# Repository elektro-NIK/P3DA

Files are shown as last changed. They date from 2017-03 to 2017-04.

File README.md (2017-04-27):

# P3DA

This is RGB controller based on Arduino board.

Features:
- 6 RGB chanels (18 mono-chanels)
- common anode or cathode
- light, effect, sound, external backlight modes
- white balance, gamma correction

Install:
- `pip3 install PyQt5` and `python3 setup.py install` for use in your system
- or `pip3 install -e .` for install all necessary modules

Using: 
- `./software/main.py` for starting
- `/software/test.py` test rainbow ilumination on 0 channel

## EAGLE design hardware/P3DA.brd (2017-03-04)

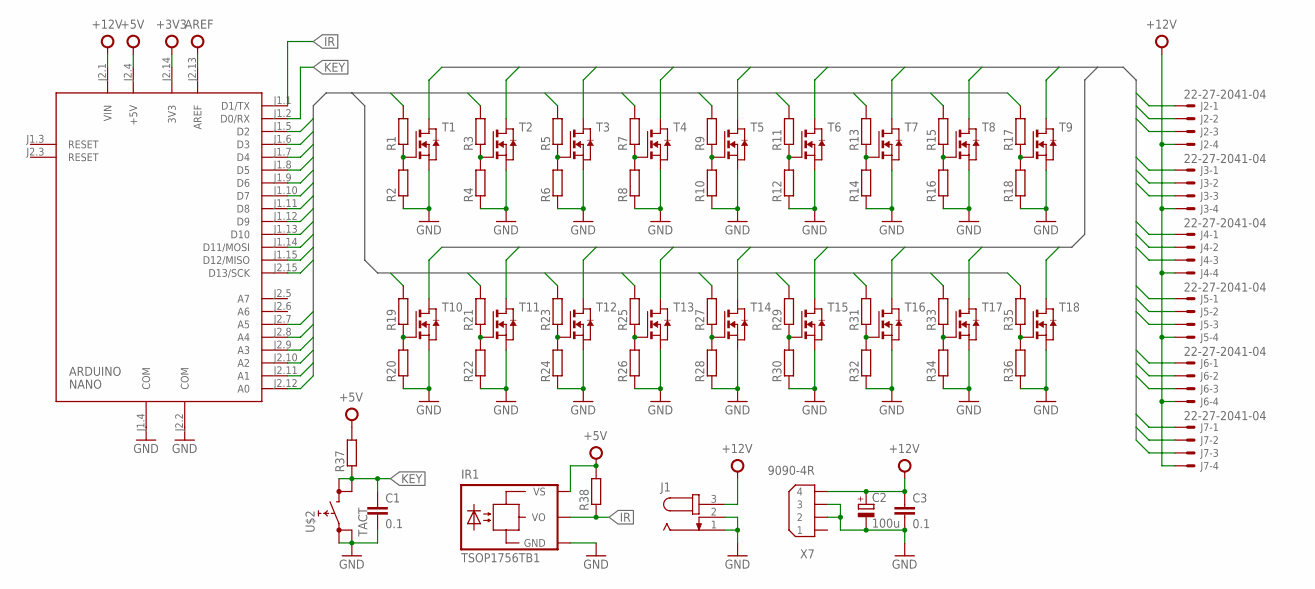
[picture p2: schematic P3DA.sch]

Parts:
ARDUINO: NANO; ARDUINO_NANO2
C1: 0.1; C0805
C2: 100u; E5-13
C3: 0.1; C1206
IR1: TSOP1756TB1; TSOP17_TB1
J1: JACK-PLUG1; SPC4078
J2, J3, J4, J5, J6, J7: 22-27-2041-04; 6410-04
R1, R2, R3, R4, R5, R6, R7, R8, R9, R10, R11, R12, R13, R14, R15, R16, R17, R18, R19, R20, R21, R22, R23, R24, R25, R26, R27, R28, R29, R30, R31, R32, R33, R34, R35, R36, R37, R38: R-EU_R0805; R0805
T1, T2, T3, T4, T5, T6, T7, T8, T9, T10, T11, T12, T13, T14, T15, T16, T17, T18: NMOSSOT23; SOT-23
U$2: TACT; TL1105
X7: 9090-4R

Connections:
+3V3: ARDUINO.J2.14 (3V3)
+5V: ARDUINO.J2.4 (+5V), IR1.VS, R37.2, R38.2
+12V: ARDUINO.J2.1 (VIN), C2.+, C3.1, J1.3, J2.4, J3.4, J4.4, J5.4, J6.4, J7.4, X7.4
AREF: ARDUINO.J2.13 (AREF)
B1: J2.1, T3.1 (D)
B2: J3.1, T6.1 (D)
B3: J4.1, T9.1 (D)
B4: J5.1, T12.1 (D)
B5: J6.1, T15.1 (D)
B6: J7.1, T18.1 (D)
B_IN1: ARDUINO.J1.5 (D2), R5.2
B_IN2: ARDUINO.J1.8 (D5), R11.2
B_IN3: ARDUINO.J1.11 (D8), R17.2
B_IN4: ARDUINO.J2.9 (A3), R23.2
B_IN5: ARDUINO.J2.12 (A0), R29.2
B_IN6: ARDUINO.J1.15 (D12/MISO), R35.2
G1: J2.3, T2.1 (D)
G2: J3.3, T5.1 (D)
G3: J4.3, T8.1 (D)
G4: J5.3, T11.1 (D)
G5: J6.3, T14.1 (D)
G6: J7.3, T17.1 (D)
GND: ARDUINO.J1.4 (COM), ARDUINO.J2.2 (COM), C1.2, C2.-, C3.2, IR1.GND, J1.1, J1.2, R2.1, R4.1, R6.1, R8.1, R10.1, R12.1, R14.1, R16.1, R18.1, R20.1, R22.1, R24.1, R26.1, R28.1, R30.1, R32.1, R34.1, R36.1, T1.2 (S), T2.2 (S), T3.2 (S), T4.2 (S), T5.2 (S), T6.2 (S), T7.2 (S), T8.2 (S), T9.2 (S), T10.2 (S), T11.2 (S), T12.2 (S), T13.2 (S), T14.2 (S), T15.2 (S), T16.2 (S), T17.2 (S), T18.2 (S), U$2.1 (0), U$2.3 (0), X7.2, X7.3
G_IN1: ARDUINO.J1.7 (D4), R3.2
G_IN2: ARDUINO.J1.10 (D7), R9.2
G_IN3: ARDUINO.J1.13 (D10), R15.2
G_IN4: ARDUINO.J2.7 (A5), R21.2
G_IN5: ARDUINO.J2.10 (A2), R27.2
G_IN6: ARDUINO.J2.15 (D13/SCK), R33.2
IR: ARDUINO.J1.1 (D1/TX), IR1.VO, R38.1
KEY: ARDUINO.J1.2 (D0/RX), C1.1, R37.1, U$2.2 (1), U$2.4 (1)
unnamed: R7.1, R8.2, T4.3 (G)
unnamed: R9.1, R10.2, T5.3 (G)
unnamed: R5.1, R6.2, T3.3 (G)
unnamed: R11.1, R12.2, T6.3 (G)
unnamed: R13.1, R14.2, T7.3 (G)
unnamed: R15.1, R16.2, T8.3 (G)
unnamed: R17.1, R18.2, T9.3 (G)
unnamed: R19.1, R20.2, T10.3 (G)
unnamed: R21.1, R22.2, T11.3 (G)
unnamed: R23.1, R24.2, T12.3 (G)
unnamed: R25.1, R26.2, T13.3 (G)
unnamed: R27.1, R28.2, T14.3 (G)
unnamed: R29.1, R30.2, T15.3 (G)
unnamed: R31.1, R32.2, T16.3 (G)
unnamed: R33.1, R34.2, T17.3 (G)
unnamed: R35.1, R36.2, T18.3 (G)
unnamed: R1.1, R2.2, T1.3 (G)
unnamed: R3.1, R4.2, T2.3 (G)
R1: J2.2, T1.1 (D)
R2: J3.2, T4.1 (D)
R3: J4.2, T7.1 (D)
R4: J5.2, T10.1 (D)
R5: J6.2, T13.1 (D)
R6: J7.2, T16.1 (D)
R_IN1: ARDUINO.J1.6 (D3), R1.2
R_IN2: ARDUINO.J1.9 (D6), R7.2
R_IN3: ARDUINO.J1.12 (D9), R13.2
R_IN4: ARDUINO.J2.8 (A4), R19.2
R_IN5: ARDUINO.J2.11 (A1), R25.2
R_IN6: ARDUINO.J1.14 (D11/MOSI), R31.2

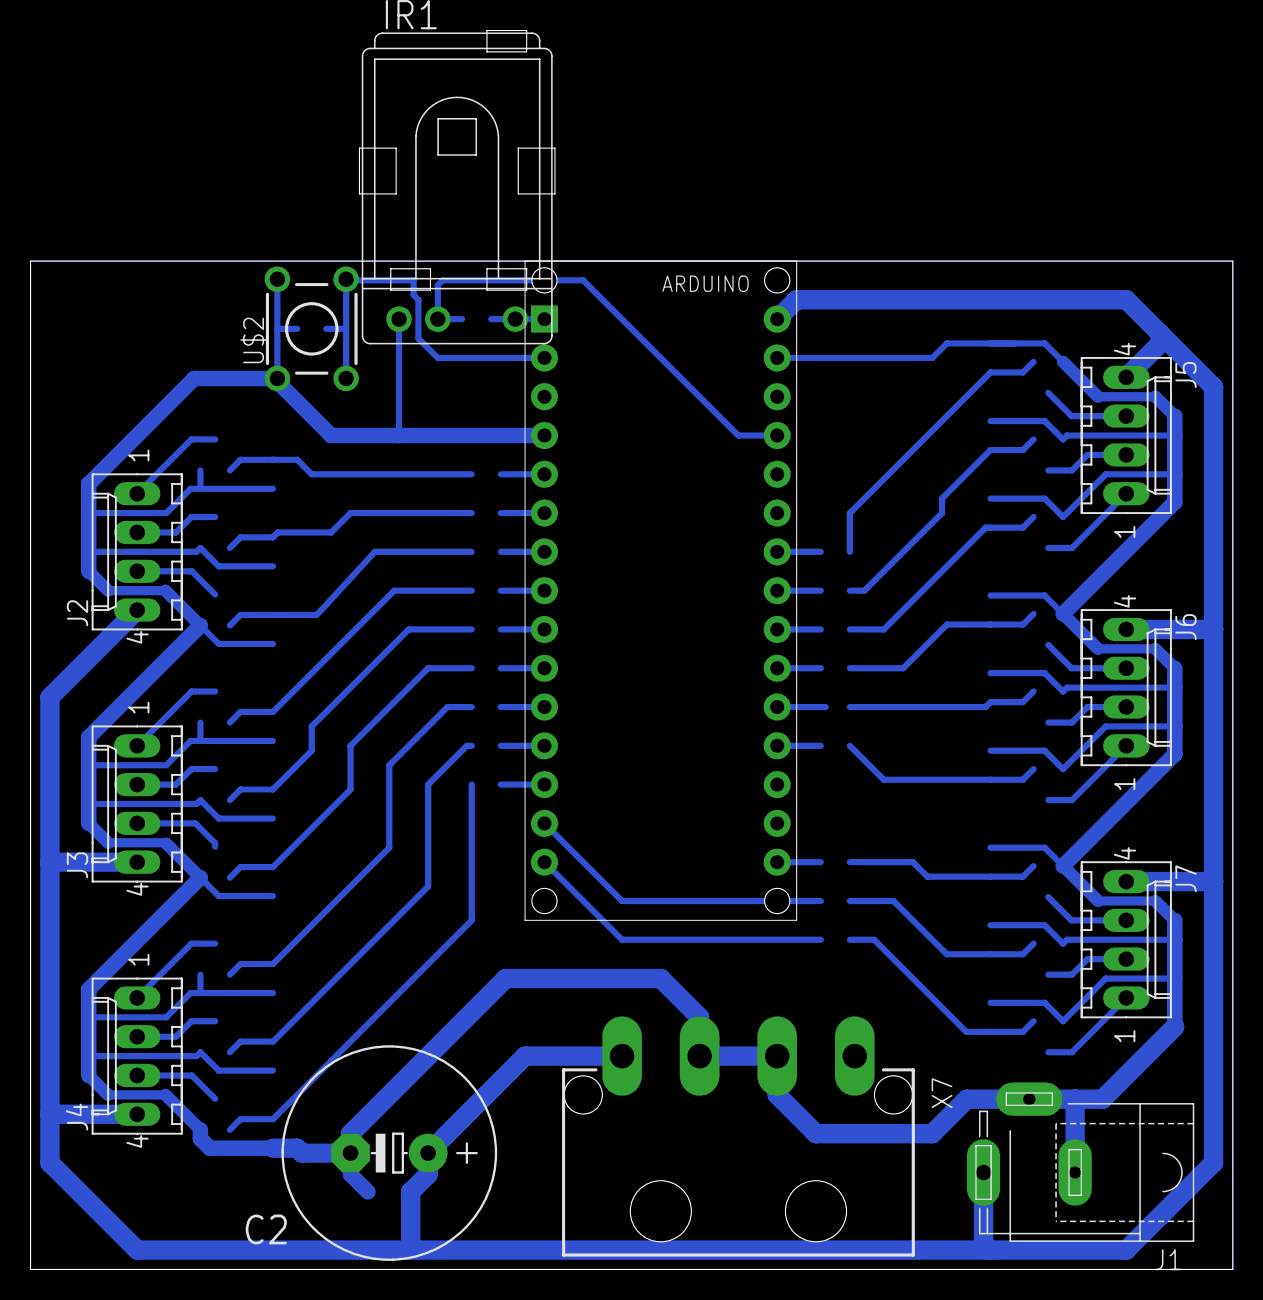
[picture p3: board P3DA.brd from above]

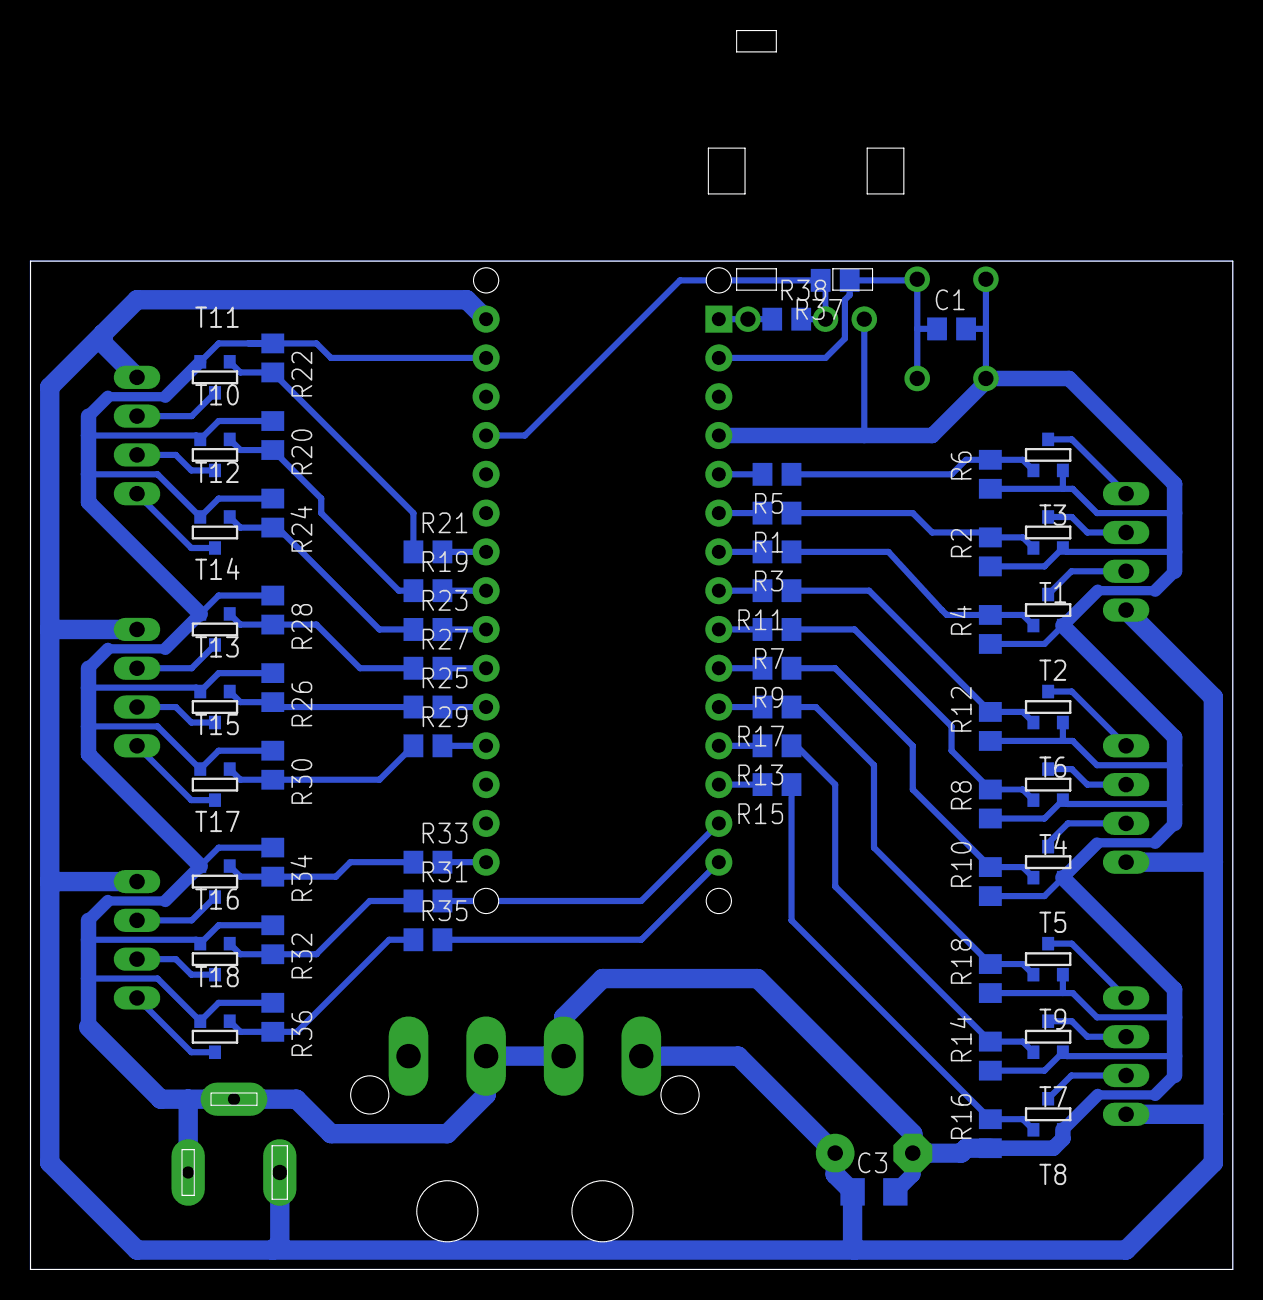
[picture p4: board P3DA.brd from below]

Board: 2 copper layers, 78.7 x 66.0 mm, 70 parts (58 on the bottom side), 59 nets.

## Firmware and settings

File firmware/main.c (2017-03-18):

/*@{*/ // Ports setup
#define DDR_RED0    DDRD
#define DDR_GREEN0  DDRD
#define DDR_BLUE0   DDRD
#define DDR_RED1    DDRD
#define DDR_GREEN1  DDRD
#define DDR_BLUE1   DDRD
#define DDR_RED2    DDRB
#define DDR_GREEN2  DDRB
#define DDR_BLUE2   DDRB
#define DDR_RED3    DDRB
#define DDR_GREEN3  DDRB
#define DDR_BLUE3   DDRB
#define DDR_RED4    DDRC
#define DDR_GREEN4  DDRC
#define DDR_BLUE4   DDRC
#define DDR_RED5    DDRC
#define DDR_GREEN5  DDRC
#define DDR_BLUE5   DDRC

#define PORT_RED0   PORTD
#define PORT_GREEN0 PORTD
#define PORT_BLUE0  PORTD
#define PORT_RED1   PORTD
#define PORT_GREEN1 PORTD
#define PORT_BLUE1  PORTD
#define PORT_RED2   PORTB
#define PORT_GREEN2 PORTB
#define PORT_BLUE2  PORTB
#define PORT_RED3   PORTB
#define PORT_GREEN3 PORTB
#define PORT_BLUE3  PORTB
#define PORT_RED4   PORTC
#define PORT_GREEN4 PORTC
#define PORT_BLUE4  PORTC
#define PORT_RED5   PORTC
#define PORT_GREEN5 PORTC
#define PORT_BLUE5  PORTC

#define RED0        PD3
#define GREEN0      PD4
#define BLUE0       PD2
#define RED1        PD6
#define GREEN1      PD7
#define BLUE1       PD5
#define RED2        PB1
#define GREEN2      PB2
#define BLUE2       PB0
#define RED3        PB3
#define GREEN3      PB5
#define BLUE3       PB4
#define RED4        PC1
#define GREEN4      PC2
#define BLUE4       PC0
#define RED5        PC4
#define GREEN5      PC5
#define BLUE5       PC3
/*@}*/

/*@{*/ // LEDs setup
#define RED         0
#define GREEN       1
#define BLUE        2
#define CATHODE     0
#define ANODE       1

#define COLORS      3
#define CHANELS     6
#define COMMON      CATHODE                 // Common electrode in RGB. CATHODE or ANODE
/*@}*/

/*@{*/ // PWM setup
#define PWMDEPTH    9
#define MAXPWM      511                 // (2^PWMDEPTH) - 1
/*@}*/

/*@{*/ // USART setup
#define BAUD 38400

#define USART_RX_BUFFER_SIZE 128            // 2,4,8,16,32,64,128 or 256 bytes
#define USART_TX_BUFFER_SIZE 128            // 2,4,8,16,32,64,128 or 256 bytes
#define USART_RX_BUFFER_MASK (USART_RX_BUFFER_SIZE - 1)
#define USART_TX_BUFFER_MASK (USART_TX_BUFFER_SIZE - 1)

#if (USART_RX_BUFFER_SIZE & USART_RX_BUFFER_MASK)
#error RX buffer size is not a power of 2
#endif
#if (USART_TX_BUFFER_SIZE & USART_TX_BUFFER_MASK)
#error TX buffer size is not a power of 2
#endif
/*@}*/

#include <avr/io.h>
#include <avr/interrupt.h>
#include <util/setbaud.h>

/*@{*/ // Global variables
static uint8_t USART_RxBuf[USART_RX_BUFFER_SIZE];
static volatile uint8_t USART_RxHead;
static volatile uint8_t USART_RxTail;
static uint8_t USART_TxBuf[USART_TX_BUFFER_SIZE];
static volatile uint8_t USART_TxHead;
static volatile uint8_t USART_TxTail;

volatile uint16_t leds[COLORS][CHANELS];              // Values RGB LEDs. User changeble
uint16_t leds_buff[COLORS][CHANELS];         // Protected buffer RGB values. Program use only
volatile uint16_t countPWM = 0;                       // Counter for software PWM
/*@}*/

/*@{*/ // Functions section

void InitPorts() {
    DDR_RED0 |= 1<<RED0;
    DDR_RED1 |= 1<<RED1;
    DDR_RED2 |= 1<<RED2;
    DDR_RED3 |= 1<<RED3;
    DDR_RED4 |= 1<<RED4;
    DDR_RED5 |= 1<<RED5;
    DDR_GREEN0 |= 1<<GREEN0;
    DDR_GREEN1 |= 1<<GREEN1;
    DDR_GREEN2 |= 1<<GREEN2;
    DDR_GREEN3 |= 1<<GREEN3;
    DDR_GREEN4 |= 1<<GREEN4;
    DDR_GREEN5 |= 1<<GREEN5;
    DDR_BLUE0 |= 1<<BLUE0;
    DDR_BLUE1 |= 1<<BLUE1;
    DDR_BLUE2 |= 1<<BLUE2;
    DDR_BLUE3 |= 1<<BLUE3;
    DDR_BLUE4 |= 1<<BLUE4;
    DDR_BLUE5 |= 1<<BLUE5;
}

void USART0_Init() {
    UBRR0H = UBRRH_VALUE;
    UBRR0L = UBRRL_VALUE;
    #if USE_2X
    UCSR0A |= 1<<U2X0;
    #else
    UCSR0A &= ~(1<<U2X0);
    #endif
    UCSR0B |= 1<<RXEN0 | 1<<TXEN0 | 1<<RXCIE0;                      // Enable RX & TX, enable interrupt for end of RX
    USART_RxTail = 0;
    USART_RxHead = 0;
    USART_TxTail = 0;
    USART_TxHead = 0;
}

void Init() {
    InitPorts();
    TCCR0B |= 1<<CS01;                      // F_T0 = F_CPU / 8
    TIMSK0 |= 1<<TOIE0;
    USART0_Init();
}

uint8_t USART0_Receive() {
    uint8_t tmptail;
    while (USART_RxHead == USART_RxTail) {}                         // Wait for incomming data
    tmptail = (USART_RxTail + 1) & USART_RX_BUFFER_MASK;        // Calculate buffer index
    USART_RxTail = tmptail;                                     // Store new index
    return USART_RxBuf[tmptail];
}

void USART0_Transmit (uint8_t data) {
    uint8_t tmphead;
    tmphead = (USART_TxHead + 1) & USART_TX_BUFFER_MASK;            // Calculate buffer index
    while (tmphead == USART_TxTail) {}                              // Wait for free space in buffer
    USART_TxBuf[tmphead] = data;
    USART_TxHead = tmphead;                                         // Store new index
    UCSR0B |= 1<<UDRIE0;
}

uint8_t DataInReceiveBuffer() {
    return (USART_RxHead != USART_RxTail);                          // Return 0 (FALSE) if the receive buffer is empty
}

uint8_t hex2int(uint8_t hex) {
    if (hex >= '0' && hex <= '9') return hex -'0';
    else if (hex >= 'a' && hex <= 'f') return hex - 'a' + 10;
    else if (hex >= 'A' && hex <= 'F') return hex - 'A' + 10;
    else return 0;
}

uint8_t char2int(uint8_t x) {
    if (x >= '0' && x <= '9') return x - '0';
    else return 0;
}

/*@}*/

int main() {
    Init();
    sei();
    while(1){
        if (DataInReceiveBuffer()) {
            uint8_t temp = USART0_Receive();
            if (temp == '#') {
                    temp = USART0_Receive();
                    switch(temp) {
                        case 'S':
                            temp = char2int(USART0_Receive());
                            uint8_t buf[9];
                            for (uint8_t i=0; i<9; i++) {
                                buf[i] = hex2int(USART0_Receive());
                            }
                            leds[RED][temp]   = (buf[0] << 8 | buf[1] << 4 | buf[2]) & 0x1FF;
                            leds[GREEN][temp] = (buf[3] << 8 | buf[4] << 4 | buf[5]) & 0x1FF;
                            leds[BLUE][temp]  = (buf[6] << 8 | buf[7] << 4 | buf[8]) & 0x1FF;
                            break;
                        case 'T':
                            USART0_Transmit('#');
                            USART0_Transmit('O');
                            USART0_Transmit('K');
                        default:
                            break;
                    }
            }
        }
    }
}

/*@{*/ // Interrupts section

ISR (TIMER0_OVF_vect) {
    TCNT0 = 200;
    if (countPWM++ == MAXPWM) {
        countPWM = 0;
        for (uint8_t i=0; i<COLORS; i++) {
            for (uint8_t j=0; j<CHANELS; j++) {
                leds_buff[i][j] = leds[i][j];
            }
        }
        // Common anode or common cathode
#if COMMON == CATHODE
    #if CHANELS > 0
        if (leds_buff[RED][0])     PORT_RED0   |= 1<<RED0;
        if (leds_buff[GREEN][0])   PORT_GREEN0 |= 1<<GREEN0;
        if (leds_buff[BLUE][0])    PORT_BLUE0  |= 1<<BLUE0;
    #endif
    #if CHANELS > 1
        if (leds_buff[RED][1])     PORT_RED1   |= 1<<RED1;
        if (leds_buff[GREEN][1])   PORT_GREEN1 |= 1<<GREEN1;
        if (leds_buff[BLUE][1])    PORT_BLUE1  |= 1<<BLUE1;
    #endif
    #if CHANELS > 2
        if (leds_buff[RED][2])     PORT_RED2   |= 1<<RED2;
        if (leds_buff[GREEN][2])   PORT_GREEN2 |= 1<<GREEN2;
        if (leds_buff[BLUE][2])    PORT_BLUE2  |= 1<<BLUE2;
    #endif
    #if CHANELS > 3
        if (leds_buff[RED][3])     PORT_RED3   |= 1<<RED3;
        if (leds_buff[GREEN][3])   PORT_GREEN3 |= 1<<GREEN3;
        if (leds_buff[BLUE][3])    PORT_BLUE3  |= 1<<BLUE3;
    #endif
    #if CHANELS > 4
        if (leds_buff[RED][4])     PORT_RED4   |= 1<<RED4;
        if (leds_buff[GREEN][4])   PORT_GREEN4 |= 1<<GREEN4;
        if (leds_buff[BLUE][4])    PORT_BLUE4  |= 1<<BLUE4;
    #endif
    #if CHANELS > 5
        if (leds_buff[RED][5])     PORT_RED5   |= 1<<RED5;
        if (leds_buff[GREEN][5])   PORT_GREEN5 |= 1<<GREEN5;
        if (leds_buff[BLUE][5])    PORT_BLUE5  |= 1<<BLUE5;
    #endif
#elif COMMON == ANODE
    #if CHANELS > 0
        if (leds_buff[RED][0])     PORT_RED0   &= ~(1<<RED0);
        if (leds_buff[GREEN][0])   PORT_GREEN0 &= ~(1<<GREEN0);
        if (leds_buff[BLUE][0])    PORT_BLUE0  &= ~(1<<BLUE0);
    #endif
    #if CHANELS > 1
        if (leds_buff[RED][1])     PORT_RED1   &= ~(1<<RED1);
        if (leds_buff[GREEN][1])   PORT_GREEN1 &= ~(1<<GREEN1);
        if (leds_buff[BLUE][1])    PORT_BLUE1  &= ~(1<<BLUE1);
    #endif
    #if CHANELS > 2
        if (leds_buff[RED][2])     PORT_RED2   &= ~(1<<RED2);
        if (leds_buff[GREEN][2])   PORT_GREEN2 &= ~(1<<GREEN2);
        if (leds_buff[BLUE][2])    PORT_BLUE2  &= ~(1<<BLUE2);
    #endif
    #if CHANELS > 3
        if (leds_buff[RED][3])     PORT_RED3   &= ~(1<<RED3);
        if (leds_buff[GREEN][3])   PORT_GREEN3 &= ~(1<<GREEN3);
        if (leds_buff[BLUE][3])    PORT_BLUE3  &= ~(1<<BLUE3);
    #endif
    #if CHANELS > 4
        if (leds_buff[RED][4])     PORT_RED4   &= ~(1<<RED4);
        if (leds_buff[GREEN][4])   PORT_GREEN4 &= ~(1<<GREEN4);
        if (leds_buff[BLUE][4])    PORT_BLUE4  &= ~(1<<BLUE4);
    #endif
    #if CHANELS > 5
        if (leds_buff[RED][5])     PORT_RED5   &= ~(1<<RED5);
        if (leds_buff[GREEN][5])   PORT_GREEN5 &= ~(1<<GREEN5);
        if (leds_buff[BLUE][5])    PORT_BLUE5  &= ~(1<<BLUE5);
    #endif
#endif
    }
    // Common anode or common cathode
#if COMMON == CATHODE
    #if CHANELS > 0
    if (leds_buff[RED][0]   == countPWM)    PORT_RED0   &= ~(1<<RED0);
    if (leds_buff[GREEN][0] == countPWM)    PORT_GREEN0 &= ~(1<<GREEN0);
    if (leds_buff[BLUE][0]  == countPWM)    PORT_BLUE0  &= ~(1<<BLUE0);
    #endif
    #if CHANELS > 1
    if (leds_buff[RED][1]   == countPWM)    PORT_RED1   &= ~(1<<RED1);
    if (leds_buff[GREEN][1] == countPWM)    PORT_GREEN1 &= ~(1<<GREEN1);
    if (leds_buff[BLUE][1]  == countPWM)    PORT_BLUE1  &= ~(1<<BLUE1);
    #endif
    #if CHANELS > 2
    if (leds_buff[RED][2]   == countPWM)    PORT_RED2   &= ~(1<<RED2);
    if (leds_buff[GREEN][2] == countPWM)    PORT_GREEN2 &= ~(1<<GREEN2);
    if (leds_buff[BLUE][2]  == countPWM)    PORT_BLUE2  &= ~(1<<BLUE2);
    #endif
    #if CHANELS > 3
    if (leds_buff[RED][3]   == countPWM)    PORT_RED3   &= ~(1<<RED3);
    if (leds_buff[GREEN][3] == countPWM)    PORT_GREEN3 &= ~(1<<GREEN3);
    if (leds_buff[BLUE][3]  == countPWM)    PORT_BLUE3  &= ~(1<<BLUE3);
    #endif
    #if CHANELS > 4
    if (leds_buff[RED][4]   == countPWM)    PORT_RED4   &= ~(1<<RED4);
    if (leds_buff[GREEN][4] == countPWM)    PORT_GREEN4 &= ~(1<<GREEN4);
    if (leds_buff[BLUE][4]  == countPWM)    PORT_BLUE4  &= ~(1<<BLUE4);
    #endif
    #if CHANELS > 5
    if (leds_buff[RED][5]   == countPWM)    PORT_RED5   &= ~(1<<RED5);
    if (leds_buff[GREEN][5] == countPWM)    PORT_GREEN5 &= ~(1<<GREEN5);
    if (leds_buff[BLUE][5]  == countPWM)    PORT_BLUE5  &= ~(1<<BLUE5);
    #endif
#elif COMMON == ANODE
    #if CHANELS > 1
    if (leds_buff[RED][0]   == countPWM)    PORT_RED0   |= 1<<RED0;
    if (leds_buff[GREEN][0] == countPWM)    PORT_GREEN0 |= 1<<GREEN0;
    if (leds_buff[BLUE][0]  == countPWM)    PORT_BLUE0  |= 1<<BLUE0;
    #endif
    #if CHANELS > 1
    if (leds_buff[RED][1]   == countPWM)    PORT_RED1   |= 1<<RED1;
    if (leds_buff[GREEN][1] == countPWM)    PORT_GREEN1 |= 1<<GREEN1;
    if (leds_buff[BLUE][1]  == countPWM)    PORT_BLUE1  |= 1<<BLUE1;
    #endif
    #if CHANELS > 2
    if (leds_buff[RED][2]   == countPWM)    PORT_RED2   |= 1<<RED2;
    if (leds_buff[GREEN][2] == countPWM)    PORT_GREEN2 |= 1<<GREEN2;
    if (leds_buff[BLUE][2]  == countPWM)    PORT_BLUE2  |= 1<<BLUE2;
    #endif
    #if CHANELS > 3
    if (leds_buff[RED][3]   == countPWM)    PORT_RED3   |= 1<<RED3;
    if (leds_buff[GREEN][3] == countPWM)    PORT_GREEN3 |= 1<<GREEN3;
    if (leds_buff[BLUE][3]  == countPWM)    PORT_BLUE3  |= 1<<BLUE3;
    #endif
    #if CHANELS > 4
    if (leds_buff[RED][4]   == countPWM)    PORT_RED4   |= 1<<RED4;
    if (leds_buff[GREEN][4] == countPWM)    PORT_GREEN4 |= 1<<GREEN4;
    if (leds_buff[BLUE][4]  == countPWM)    PORT_BLUE4  |= 1<<BLUE4;
    #endif
    #if CHANELS > 5
    if (leds_buff[RED][5]   == countPWM)    PORT_RED5   |= 1<<RED5;
    if (leds_buff[GREEN][5] == countPWM)    PORT_GREEN5 |= 1<<GREEN5;
    if (leds_buff[BLUE][5]  == countPWM)    PORT_BLUE5  |= 1<<BLUE5;
    #endif
#endif
}

ISR (USART_RX_vect) {
    uint8_t data;
    uint8_t tmphead;
    data = UDR0;
    tmphead = (USART_RxHead + 1) & USART_RX_BUFFER_MASK;            // Calculate buffer index
    USART_RxHead = tmphead;                                         // Store new index
    if (tmphead == USART_RxTail) {
        /* ERROR! Receive buffer overflow */                        // TODO: refactory
    }
    USART_RxBuf[tmphead] = data;                                    // Store received data in buffer
}

ISR (USART_UDRE_vect) {
    uint8_t tmptail;
    if (USART_TxHead != USART_TxTail) {                             // Check if all data is transmitted
        tmptail = (USART_TxTail + 1) & USART_TX_BUFFER_MASK;        // Calculate buffer index
        USART_TxTail = tmptail;                                     // Store new index
        UDR0 = USART_TxBuf[tmptail];                                // Start transmition
    }
    else
        UCSR0B &= ~(1<<UDRIE0);
}

/*@}*/

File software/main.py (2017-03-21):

#!/usr/bin/env python3

from sys import argv, exit
from serial import Serial, serialutil
from serial import time as delay
from serial.tools import list_ports
from mainwindow_ui import Ui_MainWindow
from PyQt5.QtWidgets import QMainWindow, QApplication, QColorDialog, QWidget, QSplashScreen
from PyQt5.QtCore import QTimer, QSettings
from PyQt5.QtGui import QPixmap
from PyQt5.QtMultimedia import QAudio, QAudioInput, QAudioFormat, QAudioDeviceInfo
from pyqtgraph import setConfigOptions, mkPen


class Connection:
    def __init__(self, dev=None, baud=9600, timeout=1):
        self.dev, self.baud, self.timeout = dev, baud, timeout
        self.con = None

    def createconnection(self, dev=None):
        self.dev = dev if dev else self.dev
        try:
            self.con = Serial(port=self.dev, baudrate=self.baud, timeout=self.timeout)
        except serialutil.SerialException:
            pass

    def write(self, msg):
        self.con.write(msg.encode())

    def read(self, size=1):
        return self.con.read(size=size).decode('utf-8')

    def readline(self):
        return self.con.readline().decode('utf-8')

    def close(self):
        self.con.close()
        self.con = None

    @staticmethod
    def devicesonline():
        coms = list_ports.comports()
        return {i.device: i.description for i in coms[::-1]}

    def connectionisopen(self):
        return bool(self.con)


class Color:
    @staticmethod
    def hex2rgb(color):
        return int(color[1:3], 16), int(color[3:5], 16), int(color[5:7], 16)

    @staticmethod
    def rgb2hex(r, g, b):
        return '#{:02x}{:02x}{:02x}'.format(r, g, b)

    @staticmethod
    def plainbuttonstyle(background):
        r, g, b = Color.hex2rgb(background)
        textcolor = '#000000' if (r + 2.4 * g + b) / 4.4 > 127 else '#ffffff'
        return 'border: 0px; background-color: {}; color: {};'.format(background, textcolor)


class Effect:
    @staticmethod
    def change(colors, interval):
        return interval, colors

    @staticmethod
    def fadeblack(colors, interval):
        for i in range(len(colors)):
            colors.insert(i * 2 + 1, '#000000')
        return Effect.smooth(colors, interval / 2)

    @staticmethod
    def fadewhite(colors, interval):
        for i in range(len(colors)):
            colors.insert(i * 2 + 1, '#ffffff')
        return Effect.smooth(colors, interval / 2)

    @staticmethod
    def smooth(colors, interval):
        colors = [Color.hex2rgb(i) for i in colors]
        step = interval / 11 if interval / 11 < 255 else 255
        res = []
        for i in range(len(colors)):
            start, finish = colors[i - 1], colors[i]
            steps = {'R': (finish[0] - start[0]) / step,
                     'G': (finish[1] - start[1]) / step,
                     'B': (finish[2] - start[2]) / step}
            r, g, b = start
            for j in range(int(step)):
                res.append(Color.rgb2hex(int(r), int(g), int(b)))
                r, g, b = r + steps['R'], g + steps['G'], b + steps['B']
        return interval / step, res

    @staticmethod
    def flash(colors, interval):
        res = []
        for i in colors:
            flash = [i]
            time = 20
            while time < interval:
                flash.append('#000000')
                time += 20
            res += flash
        return 20, res

    @staticmethod
    def strob(colors, interval):
        res = []
        for i in colors:
            flash = [i, '#000000', '#000000', '#000000', i]
            time = 20 * 5
            while time < interval:
                flash.append('#000000')
                time += 20
            res += flash
        return 20, res


class Tab:
    def __init__(self, obj):
        self.main = obj

    def enabletab(self, flag):
        pass


class TabLight(Tab):
    def __init__(self, obj):
        super().__init__(obj)
        self.rgb = [0, 0, 0]
        # connections
        self.main.ui.pushButton_color.clicked.connect(self.colorselector)
        for i in range(20):
            exec('self.main.ui.pushButton_last{:02}.clicked.connect(self.palettebutton)'.format(i + 1))
        self.connectsliders()
        self.connectdial()
        # update styles
        color = self.main.ui.pushButton_color.text()
        self.main.ui.pushButton_color.setStyleSheet(Color.plainbuttonstyle(color))
        self.updatepalette()

    def enabletab(self, flag):
        self.main.ui.groupBox_last_colors.setEnabled(flag)
        self.main.ui.groupBox_color_bright.setEnabled(flag)

    def updatepalette(self):
        colors, _ = list(), self  # in exec don't work '=' with self
        for i in range(20):
            exec('colors.append(self.main.ui.pushButton_last{:02}.text())'.format(i + 1))
            style = Color.plainbuttonstyle(colors[-1])
            exec('self.main.ui.pushButton_last{:02}.setStyleSheet("{}")'.format(i + 1, style))

    def connectsliders(self):
        self.main.ui.horizontalSlider_r.valueChanged.connect(self.slidercolor)
        self.main.ui.horizontalSlider_g.valueChanged.connect(self.slidercolor)
        self.main.ui.horizontalSlider_b.valueChanged.connect(self.slidercolor)

    def disconnectsliders(self):
        self.main.ui.horizontalSlider_r.valueChanged.disconnect(self.slidercolor)
        self.main.ui.horizontalSlider_g.valueChanged.disconnect(self.slidercolor)
        self.main.ui.horizontalSlider_b.valueChanged.disconnect(self.slidercolor)

    def connectdial(self):
        self.main.ui.dial_bright.sliderPressed.connect(self.savergb)
        self.main.ui.dial_bright.sliderMoved.connect(self.dialbright)
        self.main.ui.dial_bright.valueChanged.connect(self.dialbright)

    def disconnectdial(self):
        self.main.ui.dial_bright.sliderPressed.disconnect(self.savergb)
        self.main.ui.dial_bright.sliderMoved.disconnect(self.dialbright)
        self.main.ui.dial_bright.valueChanged.disconnect(self.dialbright)

    def palettebutton(self):
        color = self.main.sender().text()
        rgb = Color.hex2rgb(color)
        self.rgb = [*rgb]
        bright = int(sum(rgb) / 3)
        self.disconnectsliders()
        self.main.ui.horizontalSlider_r.setValue(rgb[0])
        self.main.ui.horizontalSlider_g.setValue(rgb[1])
        self.main.ui.horizontalSlider_b.setValue(rgb[2])
        self.connectsliders()
        self.main.ui.pushButton_color.setText(color)
        self.main.ui.pushButton_color.setStyleSheet(Color.plainbuttonstyle(color))
        self.disconnectdial()
        self.main.ui.dial_bright.setSliderPosition(bright)
        self.main.ui.dial_bright.setValue(bright)
        self.connectdial()
        self.main.ui.lcdNumber_bright.display(bright)
        for i in range(6):
            self.main.setcolor(*rgb, i)

    def savergb(self):
        r = self.main.ui.horizontalSlider_r.value()
        g = self.main.ui.horizontalSlider_g.value()
        b = self.main.ui.horizontalSlider_b.value()
        self.rgb = [r, g, b]
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

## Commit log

2016-09-04 Update: main.c. 0 level fixed. To fix: 255 level.
    [main.c]
2016-09-05 Add choise common electrode in RGB module
2016-09-05 10bit PWM. Add avr-size in Makefile
2016-09-10 Added & fix USART interface. TODO: protocol
    [main.c]
2016-12-16 Relocate all files.
    [P3DA.brd, P3DA.sch, untitled.brd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]
2016-12-16 Fix location Firmware files
    [main.c]
2017-02-12 Fix multiple setting color
    [main.py]
2017-02-15 Refactoring PCB and schematic
    [P3DA.brd, P3DA.sch, untitled.brd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]
2017-02-21 Sound tab done. Bug fix, refactoring.
    [main.py, mainwindow_ui.py]
2017-02-22 Fix mid slider value
    [mainwindow_ui.py]
2017-02-23 Bugfix: high frequency spinbox value
    [mainwindow_ui.py]
2017-03-04 Add border
    [P3DA.brd]
2017-03-18 Setting for latest board
2017-03-18 Update for latest board
2017-03-18 Bugfix: don't update colors on restored palette
    [main.py]
2017-03-21 Bugfix: freezing on sound effects
    [main.py]
